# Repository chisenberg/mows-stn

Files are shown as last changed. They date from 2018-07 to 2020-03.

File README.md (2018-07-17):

# MOWS
### My Own Weather Station __(station repository)__
This is the MOWS project station code and hardware repository.

### BOM <small> (Build of materials)

| Qty | Item |
|-:|:-|
| 1 | Attiny-85 |
| 5 | 10K resistor |
| 1 | 22K resistor 1% |
| 1 | 47K resistor 1% |
| 1 | 1N5817 diode |
| 1 | STX882 rf 433mhz |
| 1 | MCP1700 3.3v |
| 3 | 2500 Mah NIMH AA|

</small>

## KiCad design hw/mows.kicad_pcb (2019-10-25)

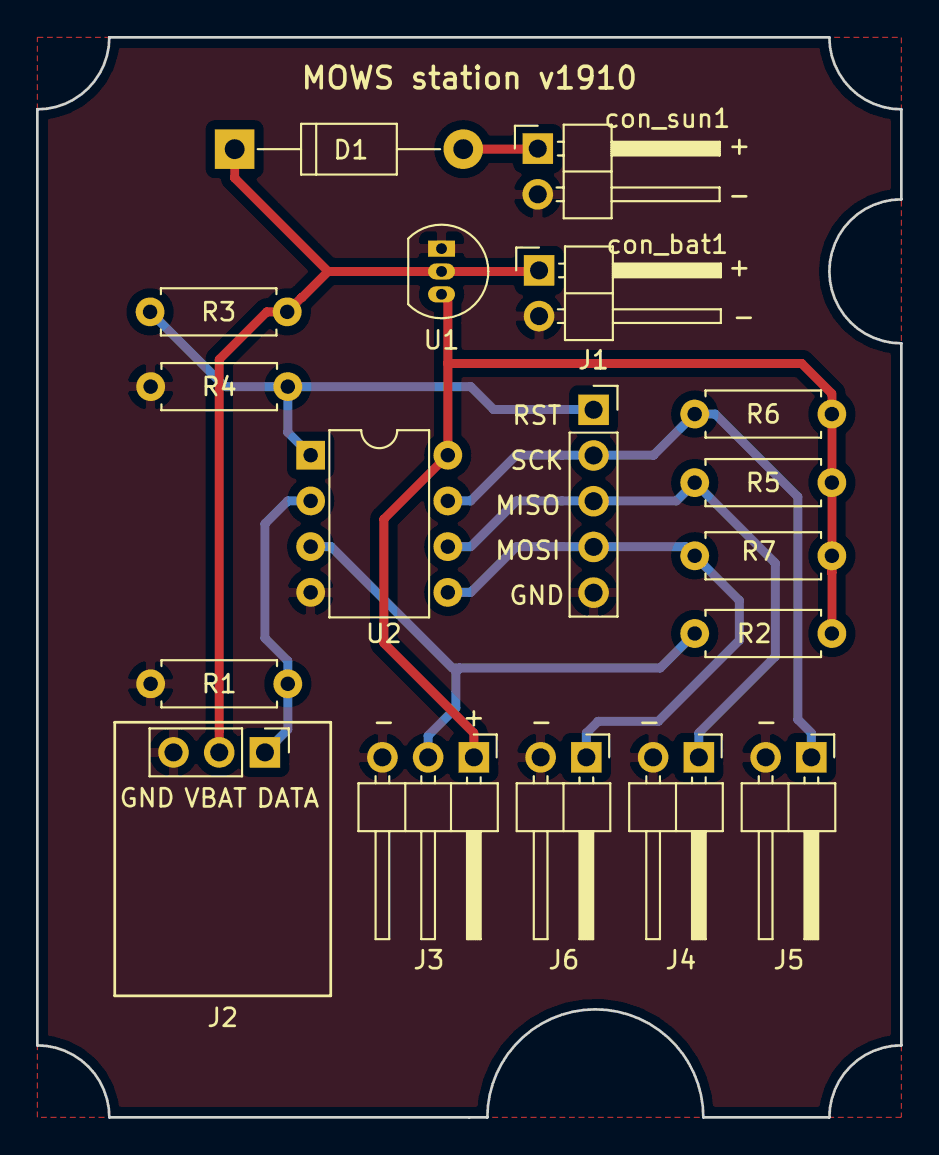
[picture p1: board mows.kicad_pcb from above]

Board: 2 copper layers, 48.0 x 60.0 mm, 18 parts (0 on the bottom side), 10 nets.

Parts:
D1: D_Schottky; D_DO-41_SOD81_P12.70mm_Horizontal
J1: Conn_01x05; PinSocket_1x05_P2.54mm_Vertical
J2: STX882; Pin_Header_Straight_1x03_Pitch2.54mm
J3: DHT22; PinHeader_1x03_P2.54mm_Horizontal
J4: WSPD; PinHeader_1x02_P2.54mm_Horizontal
J5: WDIR; PinHeader_1x02_P2.54mm_Horizontal
J6: RAIN; PinHeader_1x02_P2.54mm_Horizontal
R1, R2, R5, R6, R7: 10K; R_Axial_DIN0207_L6.3mm_D2.5mm_P7.62mm_Horizontal
R3: 22K; R_Axial_DIN0207_L6.3mm_D2.5mm_P7.62mm_Horizontal
R4: 47K; R_Axial_DIN0207_L6.3mm_D2.5mm_P7.62mm_Horizontal
U1: MCP1700-3302E_TO92; TO-92_Inline_Narrow_Oval
U2: ATTINY85-20PU; DIP-8_W7.62mm
con_bat1: BATT; PinHeader_1x02_P2.54mm_Horizontal
con_sun1: SUN; PinHeader_1x02_P2.54mm_Horizontal

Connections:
+3V3: J3.1, R2.1, R5.1, R6.1, R7.1, U1.3, U2.8
+BATT: D1.1, J2.2, R3.1, U1.2, con_bat1.1
/DHT22: J3.2, R2.2, U2.3
/MISO: J1.3, J4.1, R5.2, U2.6
/MOSI: J1.4, J6.1, R7.2, U2.5
/RFTX: J2.1, R1.1, U2.2
/RST: J1.1, R3.2, R4.1, U2.1
/SCK: J1.2, J5.1, R6.2, U2.7
GND: J1.5, J2.3, J3.3, J4.2, J5.2, J6.2, R1.2, R4.2, U1.1, U2.4, con_bat1.2, con_sun1.2
unnamed: D1.2, con_sun1.1

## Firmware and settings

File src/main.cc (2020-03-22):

#include <inttypes.h>
#include "ctimer.h"
#include "pin.h"
#include "pulse433.h"
#include "dht22.h"
#include "battery.h"
#include "interrupt.h"

// bat = (analog * (3,3/256)) * 1,45

#define MSG_SIZE 9


int main(void)
{
	
	// Pin* pinWindDir = new Pin(&PORTB, &DDRB, &PINB, 2, 0); // w_dir
	Pin* pinRf433 = new Pin(&PORTB, &DDRB, &PINB, 3); // mows_tx
	Pin* pinDht22 = new Pin(&PORTB, &DDRB, &PINB, 4); // mows_dht22

	Ctimer *ctimer = Ctimer::getTimer();
	Interrupt *interrupts = Interrupt::getInterrupt();
	DHT22 *dht22 = new DHT22(pinDht22);
	Battery *battery = new Battery();
	Pulse433 *pulse433 = new Pulse433(pinRf433);

	uint8_t *msg = (uint8_t*) calloc(MSG_SIZE, sizeof(uint8_t));

	while(1) {

		ctimer->waitMillis(5000);
		dht22->read();
		ctimer->waitMillis(500);


		// uin8_t battery
		msg[0] = battery->readVoltage();
		msg[1] = interrupts->getRain() >> 8;
		msg[2] = interrupts->getRain() & 0x00FF;
		msg[3] = dht22->temperature >> 8;
		msg[4] = dht22->temperature & 0x00FF;
		msg[5] = dht22->humidity >> 8;
		msg[6] = dht22->humidity & 0x00FF;
		msg[7] = interrupts->getWind() >> 8;
		msg[8] = interrupts->getWind() & 0x00FF;
		// here goes wind direction in the future
		//  msg[9] = windDirection();

		pulse433->sendMsg(msg, MSG_SIZE);
	}
}

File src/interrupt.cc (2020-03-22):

#include "interrupt.h"

Interrupt* Interrupt::instance = 0;
Ctimer* Interrupt::ctimer = 0;
Pin* Interrupt::pinRain = 0;
Pin* Interrupt::pinWindSpd = 0;

// counters
uint16_t Interrupt::counterRain = 0;
uint16_t Interrupt::counterWindSpd = 0;


// debounce milliseconds
uint32_t Interrupt::lastMillisRain = 0;
uint32_t Interrupt::lastMillisWindSpd = 0;

// store pins last state
uint8_t Interrupt::pinHistory = 0xFF;

Interrupt::Interrupt(){
	// pin change interrupt enable
	GIMSK |= (1 << PCIE);
	// pin change interrupt enabled for RAIN and WIND_SPD
	PCMSK |= ((1 << PCINT0) | (1 << PCINT1)); 
	// enable interrupts
	sei();
}

void Interrupt::handleInterrupt()
{
	uint32_t millis = ctimer->millis();
	uint8_t changedbits = PINB ^ pinHistory;
	pinHistory = PINB;

	// rain interrupt
	if(changedbits & (1 << PB0) && millis > lastMillisRain + 50)
	{
		counterRain++;
		lastMillisRain = millis;
	}

	// wind interrupt
	if(changedbits & (1 << PB1) && millis > lastMillisWindSpd + 50)
	{
		counterWindSpd++;
		lastMillisWindSpd = millis;
	}
}

Interrupt* Interrupt::getInterrupt()
{
	if(instance == 0) {
		instance = new Interrupt();
		ctimer = Ctimer::getTimer();
		pinRain = new Pin(&PORTB, &DDRB, &PINB, 0); // rain
		pinWindSpd = new Pin(&PORTB, &DDRB, &PINB, 1); // w_spd
		pinRain->input();
		pinWindSpd->input();
	}
	return instance;
}

uint16_t Interrupt::getRain()
{
	return counterRain;
}

uint16_t Interrupt::getWind()
{
	return counterWindSpd;
}

ISR(PCINT0_vect)
{
	Interrupt::handleInterrupt();
}

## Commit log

2018-07-17 New repository for mows station
    [mows.kicad_pcb, mows.sch, mows_old.kicad_pcb]
2018-07-17 Added bom to readme
2018-08-27 ctimer support for different clocks
    [mows.kicad_pcb, mows.sch, mows_old.kicad_pcb]
2019-10-24 Nova placa
    [mows-B_Cu.gbr, mows-B_Mask.gbr, mows-B_SilkS.gbr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]
2019-10-24 Fix missing trace
    [mows-B_Cu.gbr, mows-B_Mask.gbr, mows-B_SilkS.gbr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]
2019-10-25 pcb labels
    [mows.kicad_pcb, mows.sch]
2020-01-17 Some hardware commits
    [mows.sch]
2020-01-27 Interrupts kind of working
